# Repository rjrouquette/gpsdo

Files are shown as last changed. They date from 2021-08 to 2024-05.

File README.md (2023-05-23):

# GPSDO PTP Master

Redesign of the [Radio Astronomy Master Clock](https://github.com/rjrouquette/radio_astronomy#master-clock) as an IEEE 1588 PTP Master.

## IEEE 1588 PTP Master
- ublox MAX-8Q GPS
- MSP432E401Y
    - integrated EMAC+PHY with PTP support
    - PTP PPS generation for synchronization with GPSDO
- Software discipline of XO frequency and offset
- PPS and 1 kHz reference outputs
- POE powered w/ battery backup
- DHCP client
- NTP server
- PTP server
- SNMP server
- UDP status endpoints

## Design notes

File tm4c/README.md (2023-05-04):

# TM4C1249NCPDT Source Code

### Sections

- [Pin Assigments](#pin-assignments)
- [Support SNMP MIBs](#supported-snmp-mibs)
- [Hardware References](#hardware-references)
- [NTP References](#ntp-references)
- [SNMP References](#snmp-references)

## Pin Assignments

- PPS Timing Pins
  - PG0 (49) - ENOPPS (EMAC PPS Output)
  - PM6 (72) - T5CCP0 (Timer 5 Capture 0) tied to PG0
  - PM7 (71) - T5CCP0 (Timer 5 Capture 1) tied to GPS PPS
- GPS Data Pins
  - PJ0 (116) - U3RX (UART 3 RX) tied to GPS UART TX
  - PJ1 (117) - U3TX (UART 3 TX) tied to GPS UART RX
  - PP5 (106) - GPIO tied to GPS Reset (Active Low)

## Supported SNMP MIBs:
- 1.3.6.1.2.1.99.1.1.1 (Entity Sensor MIB)
  - 1.3.6.1.2.1.99.1.1.1.1 (Sensor Type)
  - 1.3.6.1.2.1.99.1.1.1.2 (Sensor Scale)
  - 1.3.6.1.2.1.99.1.1.1.3 (Sensor Precision)
  - 1.3.6.1.2.1.99.1.1.1.4 (Sensor Value)
  - 1.3.6.1.2.1.99.1.1.1.5 (Sensor Status)
  - 1.3.6.1.2.1.99.1.1.1.6 (Sensor Units)
  - 1.3.6.1.2.1.99.1.1.1.7 (Sensor Update Time)
  - 1.3.6.1.2.1.99.1.1.1.8 (Sensor Update Rate)
  - 1.3.6.1.2.1.99.1.1.1.9 (Sensor Name) (not-standard)

## Hardware References:
- [MSP432E401Y Datasheet](../docs/msp432e401y.pdf)
- [MSP432E401Y Manual](../docs/slau723a.pdf)
- [TM4C1249NCPDT Datasheet](../docs/tm4c1294ncpdt.pdf)
- [EK-TM4C1249XL Manual](../docs/EK-TM4C1249XL.pdf)
- [TM4C Template for Linux](https://github.com/shawn-dsilva/tm4c-linux-template)
- [TM4C-GCC](https://github.com/martinjaros/tm4c-gcc)
- [LM73 Datasheet](../docs/lm73.pdf)
- [SiT3521 Datasheet](../docs/SiT3521.pdf)

## NTP References:
- [RFC 5905: Network Time Protocol Version 4: Protocol and Algorithms Specification](https://www.ietf.org/rfc/rfc5905.html)

## SNMP References:
- [RFC 1155: Structure and Identification of Management Information for TCP/IP-based Internets](https://www.ietf.org/rfc/rfc1155.html)
- [RFC 1157: A Simple Network Management Protocol (SNMP)](https://www.ietf.org/rfc/rfc1157.html)
- [RFC 3433: Entity Sensor Management Information Base](https://www.rfc-editor.org/rfc/rfc3433.html)
- [RFC 5907: Definitions of Managed Objects for Network Time Protocol Version 4 (NTPv4)](https://www.ietf.org/rfc/rfc5907.html)
- [RFC 7577: Definition of Managed Objects for Battery Monitoring](https://www.ietf.org/rfc/rfc7577.html)
- [RFC 8173: Precision Time Protocol Version 2 (PTPv2) Management Information Base](https://www.ietf.org/rfc/rfc8173.html)
- [SMI Network Management MGMT Codes](https://www.iana.org/assignments/smi-numbers/smi-numbers.xhtml#smi-numbers-2)
- [X.690 (ANS.1)](../docs/T-REC-X.690-202102-I.pdf)

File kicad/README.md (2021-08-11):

# KiCad Projects

This directory contains the KiCad project files for the GPSDO and Ethernet boards.

---
## Ethernet

The IEEE 1588 PTP ethernet board.

Main Files:
- `ethernet.pro`
- `ethernet.sch`
- `ethernet.kicad_pcb`

---
## GPSDO

The GPSDO daughter board.

Main Files:
- `gpsdo.pro`
- `gpsdo.sch`
- `gpsdo.kicad_pcb`

---
### Errata
- 549CAAC000111BBG (25MHz) replaced with 544CAAC000112BBG (10MHz)
    - Lack of inventory for Si549
    - Si544 is reprogrammed by MSP430 to 25MHz on boot

---
### 544CAAC000112BBG
|Product |Si544|
|--- |---|
|Description |Differential/single-ended; Any frequency (I2C) XO; 0.2-1500 MHz|
|Frequency A |10 MHz|
|I2C Address (Hex Format) |0x55|
|Output Format and Supply Voltage |CMOS: 1.8 V, 2.5 V, 3.3 V|
|Temperature Stability / Total Stability |20 ppm / 50 ppm|
|OE Pin Location and Polarity |OE Pin1, Active High|
|Frequency Range |0.2 - 325 MHz (CMOS available to 250 MHz)|
|Package Option |3.2x5 mm|
|Operating Temp Range (°C) |-40 to +85|

---
### 549CAAC000111BBG
|Product |Si549|
|--- |---|
|Description |Differential/single-ended; Any frequency (I2C) XO; 0.2-1500 MHz|
|Frequency A |25 MHz|
|I2C Address (Hex Format) |0x55|
|Output Format and Supply Voltage |CMOS: 1.8 V, 2.5 V, 3.3 V|
|Temperature Stability / Total Stability |20 ppm / 50 ppm|
|OE Pin Location and Polarity |OE Pin1, Active High|
|Frequency Range |0.2 - 325 MHz (CMOS available to 250 MHz)|
|Package Option |3.2x5 mm|
|Operating Temp Range (°C) |-40 to +85|

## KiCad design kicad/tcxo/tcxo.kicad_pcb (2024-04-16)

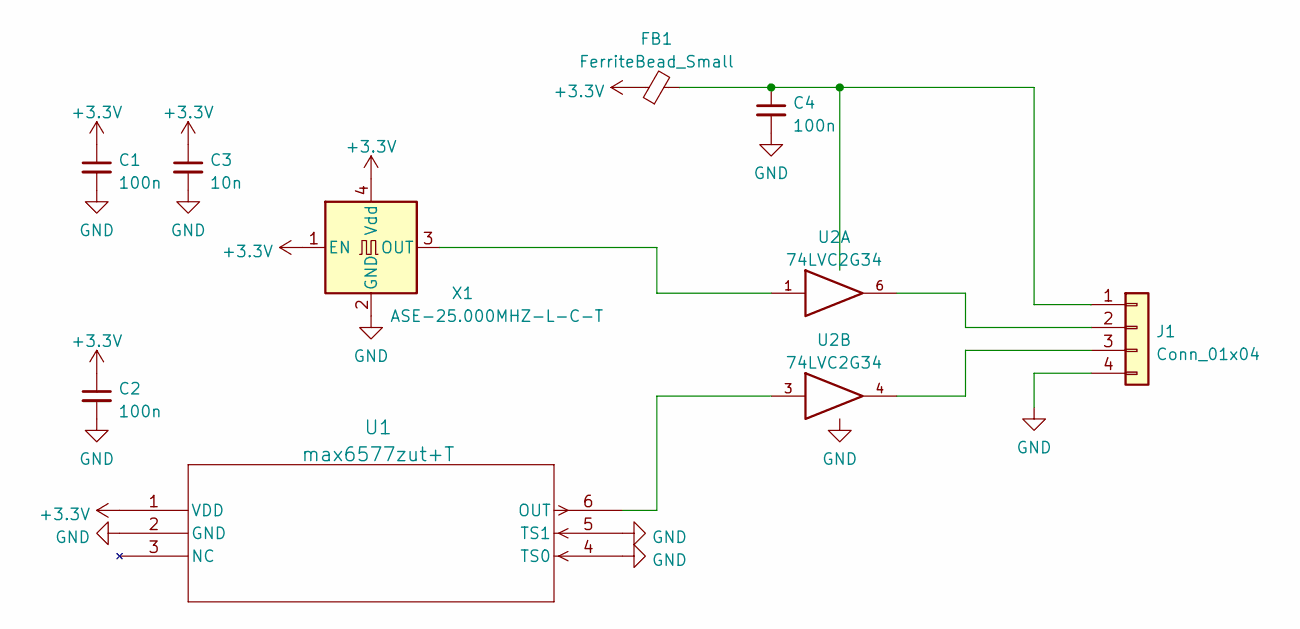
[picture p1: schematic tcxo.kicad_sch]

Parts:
C1, C2, C4: 100n; C_0805_2012Metric
C3: 10n; C_0805_2012Metric
FB1: FerriteBead_Small; R_0805_2012Metric
J1: Conn_01x04; PinHeader_1x04_P2.54mm_Vertical
U1: max6577zut+T; SOT-23-6_Handsoldering
U2: 74LVC2G34; SOT-23-6_Handsoldering
X1: ASE-25.000MHZ-L-C-T; Oscillator_SMD_Abracon_ASE-4Pin_3.2x2.5mm

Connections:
+3V3: C1.1, C2.1, C3.1, FB1.1, U1.1 (VDD), X1.1 (EN), X1.4 (Vdd)
GND: C1.2, C2.2, C3.2, C4.2, J1.4, U1.2 (GND), U1.4 (TS0), U1.5 (TS1), U2.2 (GND), X1.2 (GND)
unnamed: J1.2, U2.6
unnamed: J1.3, U2.4
unnamed: U1.6 (OUT), U2.3
unnamed: U2.1, X1.3 (OUT)
VCC: C4.1, FB1.2, J1.1, U2.5 (VCC)

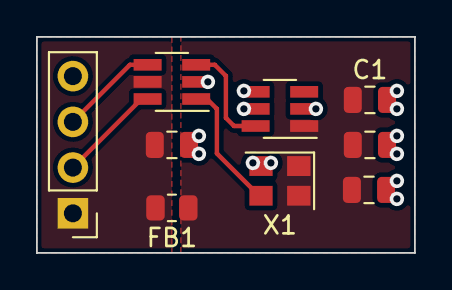
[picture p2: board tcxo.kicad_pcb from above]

Board: 2 copper layers, 21.0 x 12.0 mm, 9 parts (0 on the bottom side), 7 nets.

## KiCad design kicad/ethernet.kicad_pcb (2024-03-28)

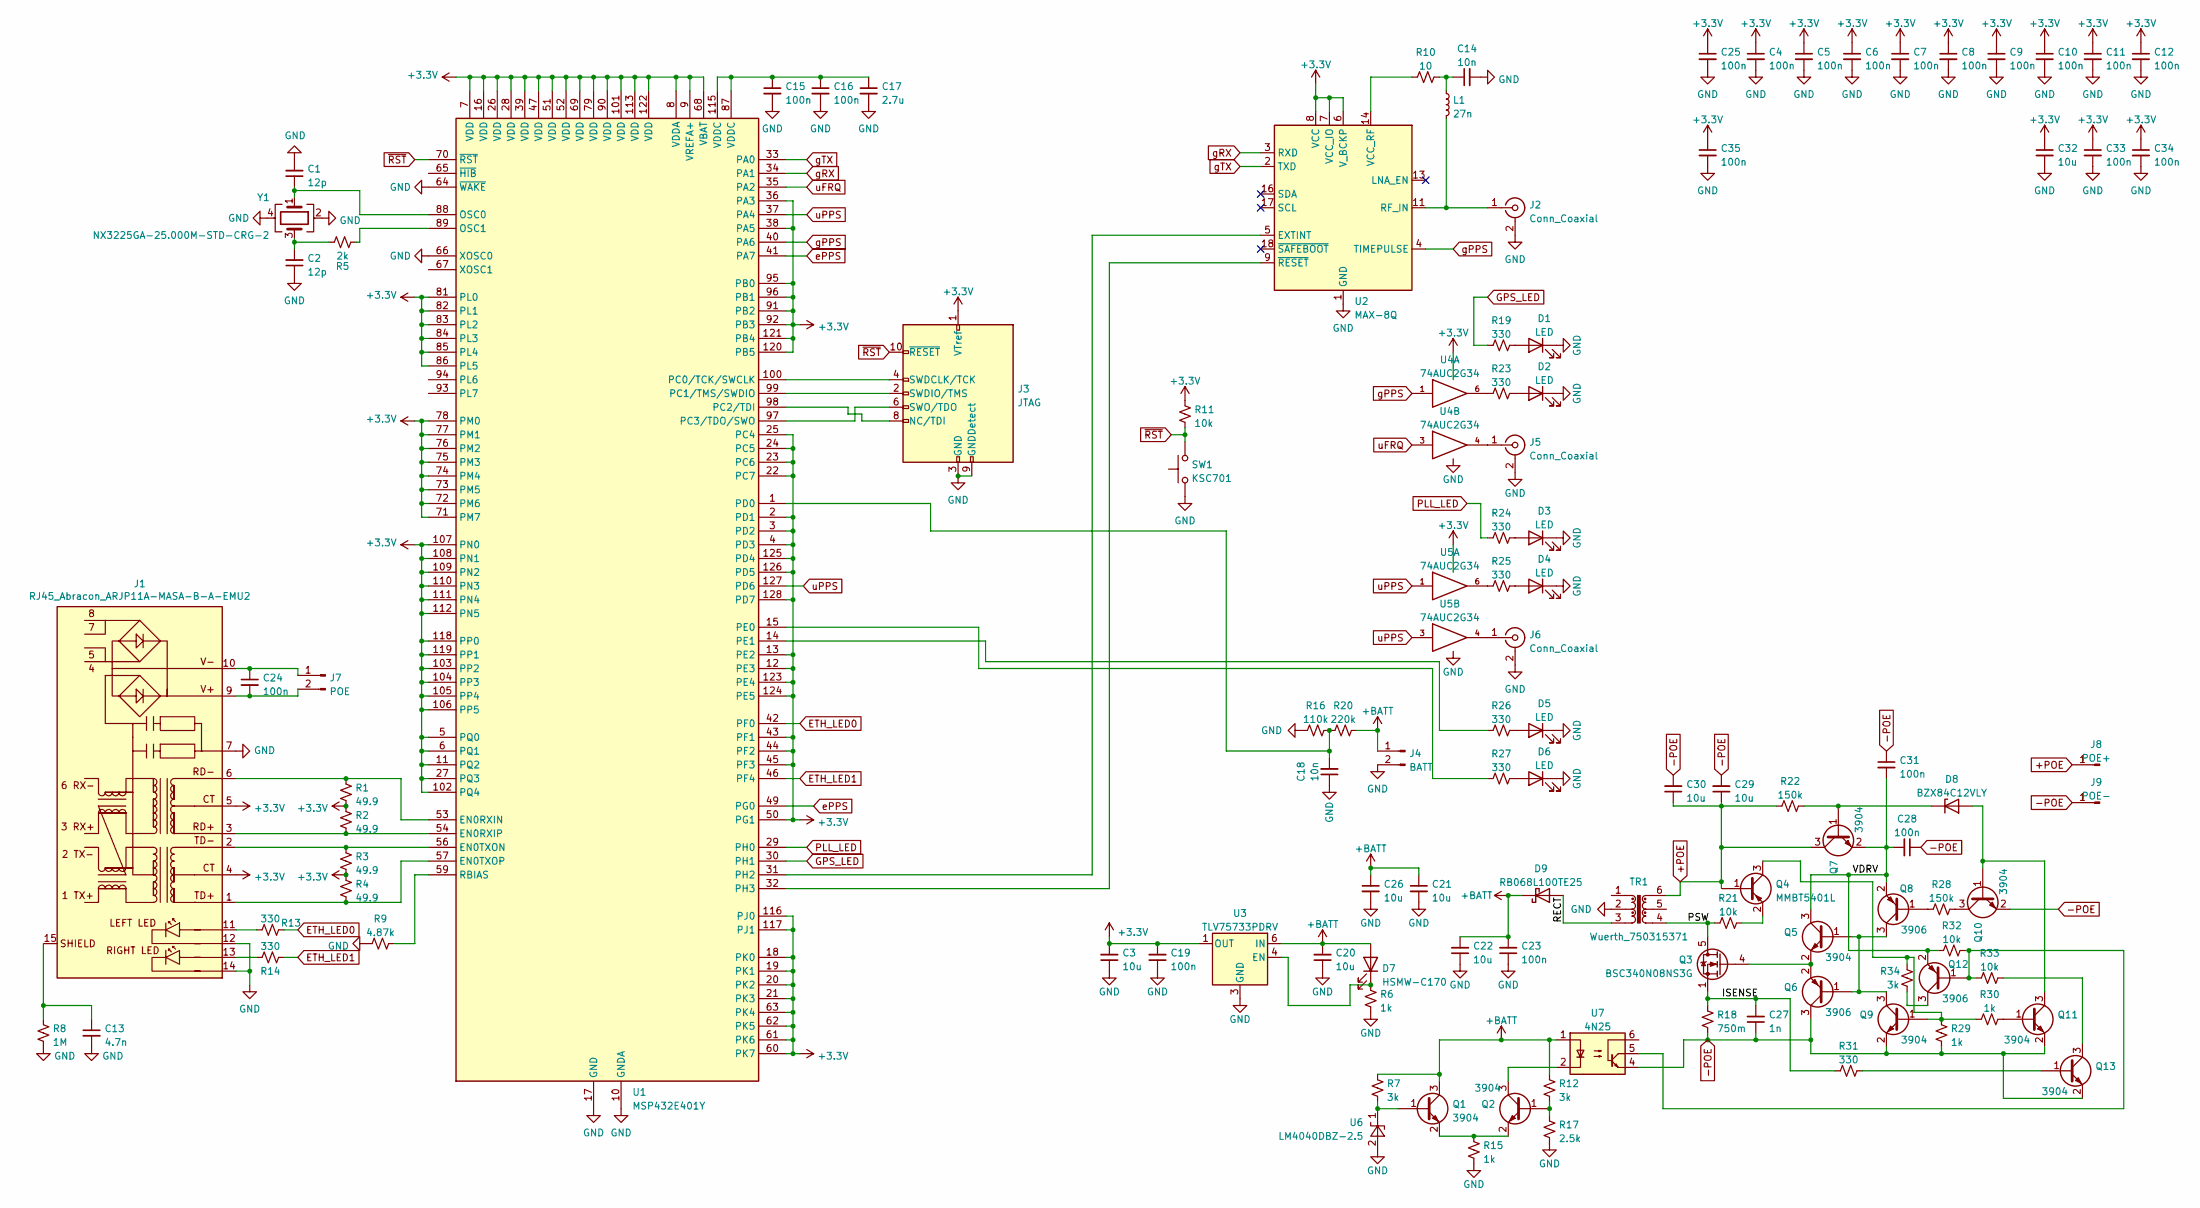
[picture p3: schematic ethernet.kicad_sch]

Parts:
C1, C2: 12p; C_0805_2012Metric
C3, C20, C21, C22, C26, C32: 10u; C_0805_2012Metric
C4, C5, C6, C7, C8, C9, C10, C11, C12, C15, C16, C19, C23, C24, C25, C28, C31, C33, C34, C35: 100n; C_0805_2012Metric
C13: 4.7n; C_0805_2012Metric
C14, C18: 10n; C_0805_2012Metric
C17: 2.7u; C_0805_2012Metric
C27: 1n; C_0805_2012Metric
C29, C30: 10u; C_1210_3225Metric
D1, D3, D5: LED; LED_D5.0mm_Horizontal_O3.81mm_Z3.0mm
D2, D4, D6: LED; LED_D5.0mm_Horizontal_O1.27mm_Z3.0mm
D7: HSMW-C170; LED_0805_2012Metric
D8: BZX84C12VLY; D_SOT-23_ANK
D9: RB068L100TE25; D_SMA
J1: RJ45_Abracon_ARJP11A-MASA-B-A-EMU2; RJ45_Abracon_ARJP11A-MA_Horizontal
J2, J5, J6: Conn_Coaxial; SMA_Molex_73251-2120_EdgeMount_Horizontal
J3: JTAG; PinHeader_2x05_P2.54mm_Vertical
J4: BATT; PinHeader_1x02_P2.54mm_Vertical
J7: POE; PinHeader_1x02_P2.54mm_Vertical
J8: POE+; Pin_D0.9mm_L10.0mm_W2.4mm_FlatFork
J9: POE-; Pin_D0.9mm_L10.0mm_W2.4mm_FlatFork
L1: 27n; L_0805_2012Metric
Q1, Q2, Q5, Q7, Q9, Q10, Q11, Q13: 3904; SOT-23
Q3: BSC340N08NS3G; TDSON-8-1
Q4: MMBT5401L; SOT-23
Q6, Q8, Q12: 3906; SOT-23
R1, R2, R3, R4: 49.9; R_0805_2012Metric
R5: 2k; R_0805_2012Metric
R6, R15, R29, R30: 1k; R_0805_2012Metric
R7, R12, R34: 3k; R_0805_2012Metric
R8: 1M; R_0805_2012Metric
R9: 4.87k; R_0805_2012Metric
R10: 10; R_0805_2012Metric
R11, R21, R32, R33: 10k; R_0805_2012Metric
R13, R14, R19, R23, R24, R25, R26, R27, R31: 330; R_0805_2012Metric
R16: 110k; R_0805_2012Metric
R17: 2.5k; R_0805_2012Metric
R18: 750m; R_1206_3216Metric
R20: 220k; R_0805_2012Metric
R22, R28: 150k; R_0805_2012Metric
SW1: KSC701; SW_Push_1P1T_NO_CK_KSC7xxJ
TR1: Wuerth_750315371; Transformer_Wuerth_750315371
U1: MSP432E401Y; LQFP-128_14x14mm_P0.4mm
U2: MAX-8Q; ublox_MAX
U3: TLV75733PDRV; WSON-6-1EP_2x2mm_P0.65mm_EP1x1.6mm
U4, U5: 74AUC2G34; SOT-23-6
U6: LM4040DBZ-2.5; SOT-23
U7: 4N25; SMDIP-6_W9.53mm
Y1: NX3225GA-25.000M-STD-CRG-2; Crystal_SMD_3225-4Pin_3.2x2.5mm

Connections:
+3V3: C3.2, C4.1, C5.1, C6.1, C7.1, C8.1, C9.1, C10.1, C11.1, C12.1, C19.2, C25.1, C32.1, C33.1, C34.1, C35.1, J1.4 (CT), J1.5 (CT), J3.1 (VTref), R1.2, R2.1, R3.2, R4.1, R11.2, U1.2 (PD1), U1.3 (PD2), U1.4 (PD3), U1.5 (PQ0), U1.6 (PQ1), U1.7 (VDD), U1.8 (VDDA), U1.9 (VREFA+), U1.11 (PQ2), U1.12 (PE3), U1.13 (PE2), U1.16 (VDD), U1.18 (PK0), U1.19 (PK1), U1.20 (PK2), U1.21 (PK3), U1.22 (PC7), U1.23 (PC6), U1.24 (PC5), U1.25 (PC4), U1.26 (VDD), U1.27 (PQ3), U1.28 (VDD), U1.36 (PA3), U1.38 (PA5), U1.39 (VDD), U1.43 (PF1), U1.44 (PF2), U1.45 (PF3), U1.47 (VDD), U1.50 (PG1), U1.51 (VDD), U1.52 (VDD), U1.60 (PK7), U1.61 (PK6), U1.62 (PK5), U1.63 (PK4), U1.68 (VBAT), U1.69 (VDD), U1.71 (PM7), U1.72 (PM6), U1.73 (PM5), U1.74 (PM4), U1.75 (PM3), U1.76 (PM2), U1.77 (PM1), U1.78 (PM0), U1.79 (VDD), U1.81 (PL0), U1.82 (PL1), U1.83 (PL2), U1.84 (PL3), U1.85 (PL4), U1.86 (PL5), U1.90 (VDD), U1.91 (PB2), U1.92 (PB3), U1.95 (PB0), U1.96 (PB1), U1.101 (VDD), U1.102 (PQ4), U1.103 (PP2), U1.104 (PP3), U1.105 (PP4), U1.106 (PP5), U1.107 (PN0), U1.108 (PN1), U1.109 (PN2), U1.110 (PN3), U1.111 (PN4), U1.112 (PN5), U1.113 (VDD), U1.116 (PJ0), U1.117 (PJ1), U1.118 (PP0), U1.119 (PP1), U1.120 (PB5), U1.121 (PB4), U1.122 (VDD), U1.123 (PE4), U1.124 (PE5), U1.125 (PD4), U1.126 (PD5), U1.128 (PD7), U2.6 (V_BCKP), U2.7 (VCC_IO), U2.8 (VCC), U3.1 (OUT), U4.5 (VCC), U5.5 (VCC)
+BATT: C20.2, C21.1, C22.2, C23.2, C26.1, D7.2 (A), D9.1 (K), J4.1, Q1.3 (C), R7.2, R12.1, R20.1, U3.6 (IN), U7.1
+POE: C29.1, C30.1, J8.1, Q4.1 (B), Q7.3 (C), R22.2, TR1.6
-POE: C27.1, C28.1, C29.2, C30.2, C31.1, J9.1, Q6.3 (C), Q9.2 (E), Q10.2 (E), Q11.2 (E), Q13.2 (E), R18.1, R29.2, U7.4
/ISENSE: C27.2, Q3.1 (S), Q3.2 (S), Q3.3 (S), R18.2, R31.2
/PSW: Q3.5 (D), R21.2, TR1.4
/RECT: D9.2 (A), TR1.3
/VDRV: C28.2, C31.2, Q5.3 (C), Q7.2 (E), Q8.2 (E), Q12.2 (E), R32.2
ETH_LED0: R13.1, U1.42 (PF0)
ETH_LED1: R14.1, U1.46 (PF4)
GND: C1.2, C2.1, C3.1, C4.2, C5.2, C6.2, C7.2, C8.2, C9.2, C10.2, C11.2, C12.2, C13.2, C14.2, C15.2, C16.2, C17.2, C18.1, C19.1, C20.1, C21.2, C22.1, C23.1, C25.2, C26.2, C32.2, C33.2, C34.2, C35.2, D1.1 (K), D2.1 (K), D3.1 (K), D4.1 (K), D5.1 (K), D6.1 (K), J1.7, J1.12 (LLED-), J1.14 (RLED-), J2.2 (Ext), J3.3 (GND), J3.5 (GND), J3.9 (GNDDetect), J4.2, J5.2 (Ext), J6.2 (Ext), R6.1, R8.1, R9.1, R15.1, R16.2, R17.1, SW1.1, TR1.2, U1.10 (GNDA), U1.17 (GND), U1.48 (GND), U1.55 (GND), U1.58 (GND), U1.64 (~WAKE), U1.66 (XOSC0), U1.80 (GND), U1.114 (GND), U2.1 (GND), U2.10 (GND), U2.12 (GND), U3.3 (GND), U3.7 (GND), U4.2 (GND), U5.2 (GND), U6.2 (A), Y1.2, Y1.4
GPS_LED: R19.2, U1.30 (PH1)
unnamed: C1.1, U1.88 (OSC0), Y1.1
unnamed: C2.2, R5.2, Y1.3
unnamed: C13.1, J1.15 (SHIELD), R8.2
unnamed: C14.1, L1.1, R10.2
unnamed: C15.1, C16.1, C17.1, U1.87 (VDDC), U1.115 (VDDC)
unnamed: C18.2, R16.1, R20.2, U1.1 (PD0)
unnamed: C24.1, J1.10 (V-), J7.1
unnamed: C24.2, J1.9 (V+), J7.2
unnamed: D1.2 (A), R19.1
unnamed: D2.2 (A), R23.1
unnamed: D3.2 (A), R24.1
unnamed: D4.2 (A), R25.1
unnamed: D5.2 (A), R26.1
unnamed: D6.2 (A), R27.1
unnamed: D7.1 (K), R6.2, U3.4 (EN)
unnamed: D8.1 (K), Q7.1 (B), R22.1
unnamed: D8.2 (A), Q10.1 (B), Q11.3 (C)
unnamed: J1.1 (TD+), R4.2, U1.57 (EN0TXOP)
unnamed: J1.2 (TD-), R3.1, U1.56 (EN0TXON)
unnamed: J1.3 (RD+), R2.2, U1.54 (EN0RXIP)
unnamed: J1.6 (RD-), R1.1, U1.53 (EN0RXIN)
unnamed: J1.11 (LLED+), R13.2
unnamed: J1.13 (RLED+), R14.2
unnamed: J2.1 (In), L1.2, U2.11 (RF_IN)
unnamed: J3.2 (SWDIO/TMS), U1.99 (PC1/TMS/SWDIO)
unnamed: J3.4 (SWDCLK/TCK), U1.100 (PC0/TCK/SWCLK)
unnamed: J3.6 (SWO/TDO), U1.97 (PC3/TDO/SWO)
unnamed: J3.8 (NC/TDI), U1.98 (PC2/TDI)
unnamed: J5.1 (In), U4.4
unnamed: J6.1 (In), U5.4
unnamed: Q1.1 (B), R7.1, U6.1 (K)
unnamed: Q1.2 (E), Q2.2 (E), R15.2
unnamed: Q2.1 (B), R12.2, R17.2
unnamed: Q2.3 (C), U7.2
unnamed: Q3.4 (G), Q5.2 (E), Q6.2 (E)
unnamed: Q4.2 (E), R21.1
unnamed: Q4.3 (C), Q9.1 (B), R29.1, R30.1, R34.1
unnamed: Q5.1 (B), Q6.1 (B), Q8.3 (C), Q9.3 (C)
unnamed: Q8.1 (B), R28.2
unnamed: Q10.3 (C), R28.1
unnamed: Q11.1 (B), R30.2
unnamed: Q12.1 (B), R32.1, R33.2, U7.5
unnamed: Q12.3 (C), R34.2
unnamed: Q13.1 (B), R31.1
unnamed: Q13.3 (C), R33.1
unnamed: R5.1, U1.89 (OSC1)
unnamed: R9.2, U1.59 (RBIAS)
unnamed: R10.1, U2.14 (VCC_RF)
unnamed: R23.2, U4.6
unnamed: R25.2, U5.6
unnamed: R26.2, U1.14 (PE1)
unnamed: R27.2, U1.15 (PE0)
unnamed: U1.31 (PH2), U2.5 (EXTINT)
unnamed: U1.32 (PH3), U2.9 (~RESET)
PLL_LED: R24.2, U1.29 (PH0)
ePPS: U1.41 (PA7), U1.49 (PG0)
gPPS: U1.40 (PA6), U2.4 (TIMEPULSE), U4.1
gRX: U1.34 (PA1), U2.3 (RXD)
gTX: U1.33 (PA0), U2.2 (TXD)
uFRQ: U1.35 (PA2), U4.3
uPPS: U1.37 (PA4), U1.127 (PD6), U5.1, U5.3
~RST: J3.10 (~RESET), R11.1, SW1.2, U1.70 (~RST)

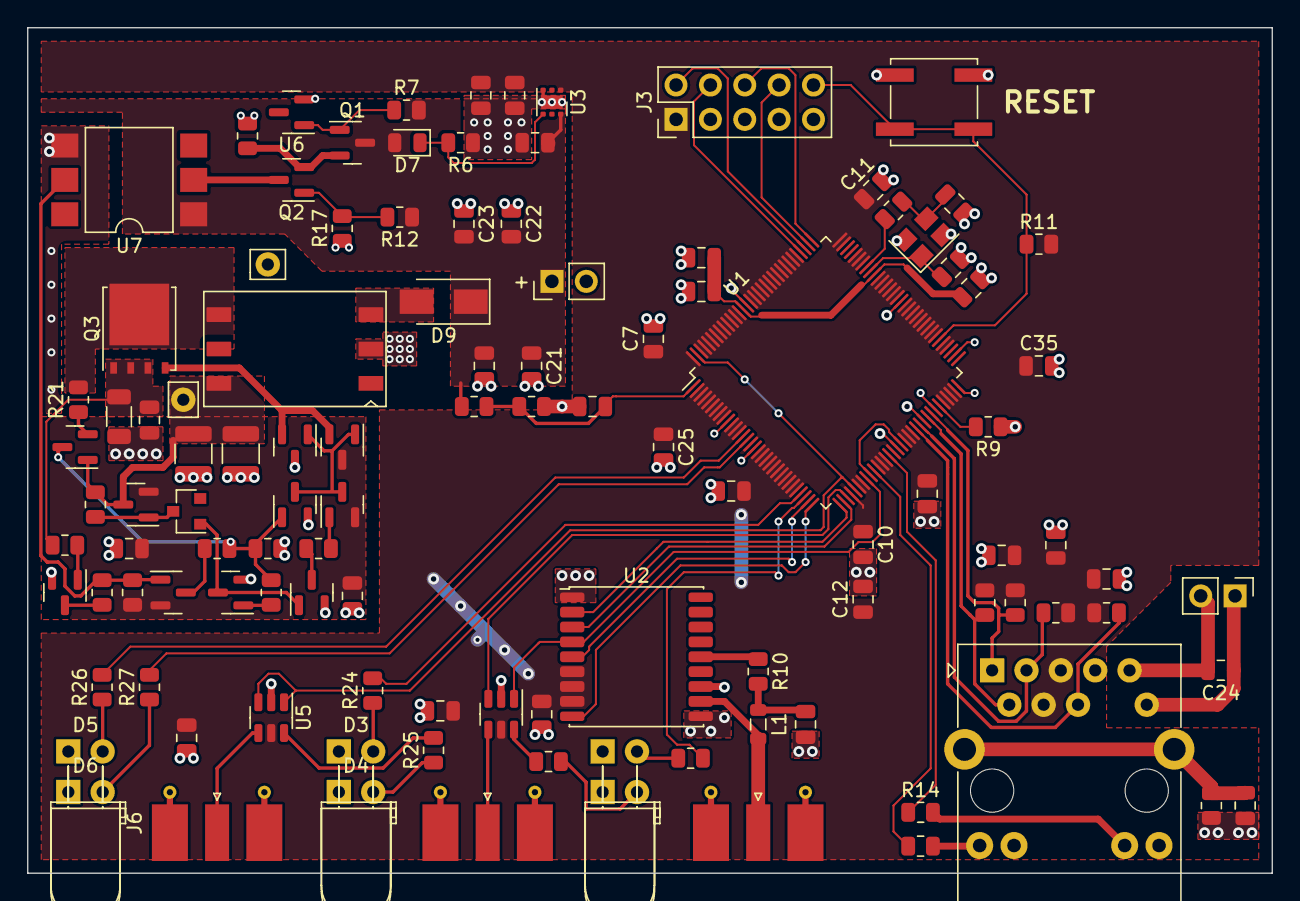
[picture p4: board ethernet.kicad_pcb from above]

Board: 2 copper layers, 92.0 x 62.5 mm, 111 parts (0 on the bottom side), 74 nets.

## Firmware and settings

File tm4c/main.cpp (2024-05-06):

/**
 * GPSDO with NTP and IEEE PTP
 * @author Robert J. Rouquette
 * @date 2022-04-13
 */

#include "gitversion.h"
#include "status.hpp"
#include "hw/eeprom.h"
#include "hw/interrupts.h"
#include "hw/sys.h"
#include "lib/delay.hpp"
#include "lib/gps.hpp"
#include "lib/led.hpp"
#include "lib/net.hpp"
#include "lib/random.hpp"
#include "lib/run.hpp"
#include "lib/clock/clock.hpp"
#include "lib/ntp/ntp.hpp"
#include "lib/ptp/ptp.hpp"
#include "lib/snmp/snmp.hpp"

#define EEPROM_FORMAT (0x00000008)

static void EEPROM_init();

extern "C"
int main() {
    // enable FPU
    CPAC.CP10 = 3;
    CPAC.CP11 = 3;

    // initialize system clock
    clock::initSystem();
    // initialize task scheduler
    initScheduler();
    // initialize status LEDs
    LED_init();
    // initialize clock
    clock::init();
    // initialize RNG
    random::init();
    // initialize EEPROM
    EEPROM_init();
    // initialize GPS
    gps::init();
    // initialize networking
    network::init();
    ntp::init();
    ptp::init();
    snmp::init();
    status::init();

    // run task scheduler
    runScheduler();
}

void Fault_Hard() {
    faultBlink(2, 1);
}

void Fault_Memory() {
    faultBlink(2, 2);
}

void Fault_Bus() {
    faultBlink(2, 3);
}

void Fault_Usage() {
    faultBlink(2, 4);
}

static void EEPROM_init() {
    // enable EEPROM
    RCGCEEPROM.EN_EEPROM = 1;
    delay::micros(1);
    EEPROM_wait();

    // verify eeprom format
    EEPROM_seek(0);
    if (EEPROM_read() != EEPROM_FORMAT) {
        // reformat EEPROM
        EEPROM_mass_erase();
        EEPROM_seek(0);
        EEPROM_write(EEPROM_FORMAT);
        EEPROM_write(VERSION_FW);
    }
}

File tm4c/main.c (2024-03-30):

/**
 * GPSDO with NTP and IEEE PTP
 * @author Robert J. Rouquette
 * @date 2022-04-13
 */

#include "gitversion.h"
#include "snmp.h"
#include "status.h"
#include "hw/eeprom.h"
#include "hw/sys.h"
#include "lib/delay.h"
#include "lib/gps.h"
#include "lib/led.h"
#include "lib/net.h"
#include "lib/rand.h"
#include "lib/run.h"
#include "lib/clk/clk.h"
#include "lib/ntp/ntp.h"
#include "lib/ptp/ptp.h"

#define EEPROM_FORMAT (0x00000006)

static void EEPROM_init();

int main(void) {
    // enable FPU
    CPAC.CP10 = 3;
    CPAC.CP11 = 3;

    // initialize system clock
    CLK_initSys();
    // initialize task scheduler
    initScheduler();
    // initialize status LEDs
    LED_init();
    // initialize clock
    CLK_init();
    // initialize RNG
    RAND_init();
    // initialize EEPROM
    EEPROM_init();
    // initialize GPS
    GPS_init();
    // initialize networking
    NET_init();
    NTP_init();
    PTP_init();
    SNMP_init();
    STATUS_init();

    // run task scheduler
    runScheduler();
}

void Fault_Hard() {
    faultBlink(2, 1);
}

void Fault_Memory() {
    faultBlink(2, 2);
}

void Fault_Bus() {
    faultBlink(2, 3);
}

void Fault_Usage() {
    faultBlink(2, 4);
}

static void EEPROM_init() {
    // enable EEPROM
    RCGCEEPROM.EN_EEPROM = 1;
    delay_us(1);
    EEPROM_wait();

    // verify eeprom format
    EEPROM_seek(0);
    const uint32_t format = EEPROM_read();
    if (format != EEPROM_FORMAT) {
        // reformat EEPROM
        EEPROM_mass_erase();
        EEPROM_seek(0);
        EEPROM_write(EEPROM_FORMAT);
        EEPROM_write(VERSION_FW);
    }
}

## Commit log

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2021-07-23 add skeleton kicad project
    [gpsdo.kicad_pcb, gpsdo.sch]
2021-07-24 add ethernet phy
    [gpsdo.kicad_pcb, gpsdo.sch]
2021-07-24 board progress
    [gpsdo.kicad_pcb, gpsdo.sch]
2021-07-26 update layout
    [gpsdo.kicad_pcb, gpsdo.sch]
2021-07-28 update board layout
    [gpsdo.kicad_pcb, gpsdo.sch]
2021-07-28 update pcb layout
    [gpsdo.kicad_pcb, gpsdo.sch]
2021-07-28 create gerber files
    [gpsdo-B_Cu.gbr, gpsdo-B_Mask.gbr, gpsdo-B_SilkS.gbr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]
2021-07-28 add I2C EERAM to README.md
2021-07-28 add DCXO shield
    [gpsdo-B_Cu.gbr, gpsdo-B_Mask.gbr, gpsdo-B_SilkS.gbr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]
2021-07-29 add fixed-point math test
    [main.cpp]
2021-07-29 add comments with decimal offset for fixed-point variables
    [main.cpp]
2021-07-29 exclude samples with bad gps lock
2021-07-29 add truncate gpsdo.csv file as example
    [gpsdo.short.csv]
2021-07-30 add pid loop code
2021-07-30 fix multiplication for PID I term
2021-07-30 add example I2C code
2021-07-30 used norm value as proxy for sample count (saves space)
2021-07-30 fix integer division by numbers above 2^31
    [main.cpp]
2021-07-31 correct precision of Si549 ADPLL adjustments
    [main.c, main.cpp]
2021-08-02 fix SBW connection
    [gpsdo.kicad_pcb, gpsdo.sch]
2021-08-02 update gerber files
    [gpsdo-B_Cu.gbr, gpsdo-B_Mask.gbr, gpsdo-B_SilkS.gbr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]
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2021-08-03 implement I2C for DCXO and temp sensor
2021-08-03 remove i2c example files
2021-08-03 implement I2C bus selection
2021-08-03 remove I2C bus selection (sub-busses not necessary)
2021-08-03 fix eeram i2c address
2021-08-03 remove extra EERAM
    [gpsdo.kicad_pcb, gpsdo.sch]
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2021-08-06 cleanup board layout
    [gpsdo-B_Cu.gbr, gpsdo-B_Mask.gbr, gpsdo-B_SilkS.gbr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]
2021-08-06 change Si549 to Si544
    [gpsdo.kicad_pcb, gpsdo.sch]
2021-08-06 optimized pid update code
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2021-08-09 use ring buffer for uart
2021-08-11 add ethernet board
    [ethernet.kicad_pcb, ethernet.sch]
2021-08-11 working on ethernet board
    [ethernet.kicad_pcb, ethernet.sch]
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2021-08-11 add QSPI flash to ethernet board
    [ethernet.kicad_pcb, ethernet.sch]
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2021-08-12 implement getter command for pid and pps trim
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2022-04-15 implement timer based delay functions
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2022-04-19 fix interrupt support
2022-05-21 drop 4-byte FCS from received frames
2022-05-23 better led activity indication
2022-05-23 replace http with snmp
    [main.c]
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2022-05-29 change temperature compensation implementation to online-learning SOM
2022-11-21 updating board
    [ethernet.kicad_pcb, ethernet.kicad_sch, gpsdo.kicad_sch]
2022-11-22 board layout
    [ethernet.kicad_pcb, ethernet.kicad_sch]
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2022-12-07 fix temperature compensation
2022-12-09 implement NTP clock steering
2022-12-09 update temperature compensation from NTP during fail-over
2022-12-17 revisit binned temperature compensation
2022-12-23 return to single regressor for temperature compensation
2023-03-31 weight ntp servers by jitter
2023-04-01 begin PTP implementation
    [ethernet.kicad_pcb, ethernet.kicad_sch]
2023-04-03 attempt to simplify temperature compensation
2023-04-11 weight by worst-case error
2023-04-15 tighten gpsdo tracking
2023-04-22 reduce pps measurement jitter
    [main.c]
2023-04-23 implement eeprom persistance of temperature compensation
2023-04-30 integrating temperature compensation into new ntp framework
2023-05-01 implement automatic reset of GPS if PPS has stalled
2023-05-01 clamp offset PLL slew rate
2023-05-03 implementing SOM filtering for temperature compensation
2023-05-03 cleanup SNMP sensor code
2023-05-03 add SOM test spreadsheet
    [som.ods]
2023-05-04 implement missing OIDs for physical sensors to comply with RFC.
2023-05-04 cleanup snmp sensor values
2023-05-04 simplify SNMP sensor code to use static registry table
2023-05-04 add simple cpp file to test som regression
    [som.ods]
2023-05-04 fix bug in regression test
    [som.ods]
2023-05-04 implement dynamic learning rate for som to minimize initial learning period
    [som.ods]
2023-05-04 testing som regression
    [som.ods]
2023-05-05 implement cubic regression in temperature compensation
2023-05-05 testing som
    [som.ods]
2023-05-06 load saved temperature compensation immediately at power-on
2023-05-06 evaluating som preformance
    [som.ods]
2023-05-06 fix temperature smoothing
2023-05-06 updating schematic
    [ethernet.kicad_pcb, ethernet.kicad_sch]
2023-05-08 update schematic
    [ethernet.kicad_pcb, ethernet.kicad_sch]
2023-05-08 simulating poe
    [ethernet.kicad_pcb]
2023-05-09 poe supply design
    [ethernet.kicad_pcb, ethernet.kicad_sch]
2023-05-09 poe power supply design
2023-05-11 test changes to compensation regression
    [som.ods]
2023-05-16 reduce GPS UART overhead
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2023-05-16 trim scheduler task slots
2023-05-16 make TX callback thread dynamic
2023-05-16 fix dynamic threads
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2023-05-17 increase UART polling rate
2023-05-18 use UART RX interrupt
2023-05-18 use UART TX interrupt
2023-05-18 board layout progress
    [ethernet.kicad_pcb, ethernet.kicad_sch]
2023-05-19 reduce ntp memory footprint
2023-05-20 enable reception of ARP broadcast packets; switch to PTPoE
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2023-05-20 reduce UART interrupt priority
2023-05-20 use software packet filtering
2023-05-23 verify som behavior
    [som.ods]
2023-05-23 remove old code
    [gpsdo.short.csv]
2023-05-23 board layout update
    [ethernet-B_Cu.gbr, ethernet-B_Mask.gbr, ethernet-B_Paste.gbr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]
2023-05-24 finishing board layout
    [ethernet-B_Cu.gbr, ethernet-B_Mask.gbr, ethernet-B_Paste.gbr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]
2023-05-26 fix sign of offset rms and stddev on initial sample
2023-05-26 improve stability of temperature compensation
    [som.ods]
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2023-05-27 reduce scheduler memory footprint
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2023-06-07 tighten possible edge case in runParse() timing
2023-06-11 increase time constant for temperature filtering
2023-06-13 tighten offset PLL
2023-09-18 remove hard-edge in sample exclusion
2024-03-28 migrating to C++
    [ethernet.kicad_pcb, ethernet.kicad_sch]
2024-04-16 faster sampling for temperature compensation
2024-04-16 add separate TCXO board
    [tcxo.kicad_pcb, tcxo.kicad_sch]
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2024-04-19 implementing new temperature sensor support
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2024-05-09 increase temperature filter time constant to two seconds
2024-05-11 cleaner initialization of temperature sensor
2024-05-16 implement linear regression filtering
2024-05-17 debugging temperature glitches
2024-05-18 fix temperature sensor startup
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2024-06-08 fix bug in temperature correction
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
